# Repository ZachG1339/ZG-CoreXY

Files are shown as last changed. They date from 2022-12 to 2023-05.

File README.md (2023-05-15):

# CoreXY

Arduino Based Core XY assembly. All 3D printed components are custom made for this assembly but are compatible with 20x20 extrusion.

The core xy method is one of many methods to move a "head" anywhere in a set MxN rectangular 2D plane. It utilizes two timing belts connected to two independent stepper motors. The belts all begin and end at the head, moving it in any direction with the combined torque of both steppers. 

## V1:

The quick background behind V1 is it was officially intended to be the arduino project for a C++ programming class. Using that as my excuse and hard 3 week timeline I tried to make a functional prototype that technically fit the project parameters, hence the joystick control and not automation.

Designed and coded to move a continuous servo attached to the head using the arduino joystick module. 

#### Known Defects:
- Motor overheating issue
  - likely caused by lack of ventilation in the motor mounts however load may have exceeded the motors I acquired for this prototype

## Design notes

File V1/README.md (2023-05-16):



### Required Materials:
(N and M are arbitrary constants)
- ~500g of PLA and 3D printer access
#### Frame:
- 20x20mm extrusion:
  - 2 (N + 1.57)" for width
  - 2 M" for length -> required only for structural stability
  - 4 2" as vertical supports
  - 1 (M - 1.6)" as the X axis
#### Linear Motion:
- [GT2 6mm timing belt](https://www.amazon.ca/gp/product/B08PKPK4D8/ref=ppx_yo_dt_b_asin_title_o00_s01?ie=UTF8&psc=1) -> length depends on extrusion length -> approximately 2M + 2N 
- [8 bearing idlers](https://www.amazon.ca/gp/product/B07P9M6BRC/ref=ppx_yo_dt_b_asin_title_o00_s01?ie=UTF8&psc=1) (5mm bore, 12mm inner diameter, 18mm outer diameter)
- [2 GT2 pulleys](https://www.amazon.ca/gp/product/B08PKPK4D8/ref=ppx_yo_dt_b_asin_title_o00_s01?ie=UTF8&psc=1)
- [9 Bearing wheels](https://www.amazon.ca/gp/product/B07Q5WN3GK/ref=ppx_yo_dt_b_asin_title_o00_s00?ie=UTF8&psc=1)
- 11 M5 40mm bolts
- 18 M5 nuts or 9 M5 lock nuts
- 4 13mm segements of smooth 5mm diameter shaft

(note: M5 items can be comfortably replaced with 3/16" equivalents)


#### Electrical:
- 2 identical NEMA 17 stepper motors
- Arduino Uno R3 or Mega R3
- DC Power Supply -> compatible with motors and drivers
- Generous supply of F-M and M-M DuPont (jumper) wires -> at least 6 and 10 respectively

## Additional Materials:
- Adafruit Motor Shield V2 -> max per motor current 1.2 A
  - [Adafruit Documentation](https://learn.adafruit.com/adafruit-motor-shield-v2-for-arduino)
- 1 [SG90 servo motor](https://www.amazon.ca/Micro-Servos-Helicopter-Airplane-Controls/dp/B07MLR1498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)
- 5 F-M jumper wires
- 1 Arduino joystick module

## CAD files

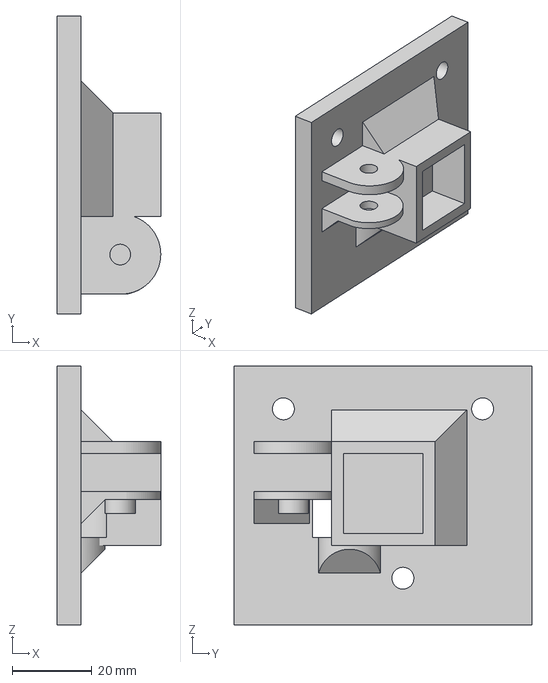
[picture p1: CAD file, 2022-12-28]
V1/Print Files/V1-2_L Carrage.3mf
26.0 x 74.8 x 65.0 mm

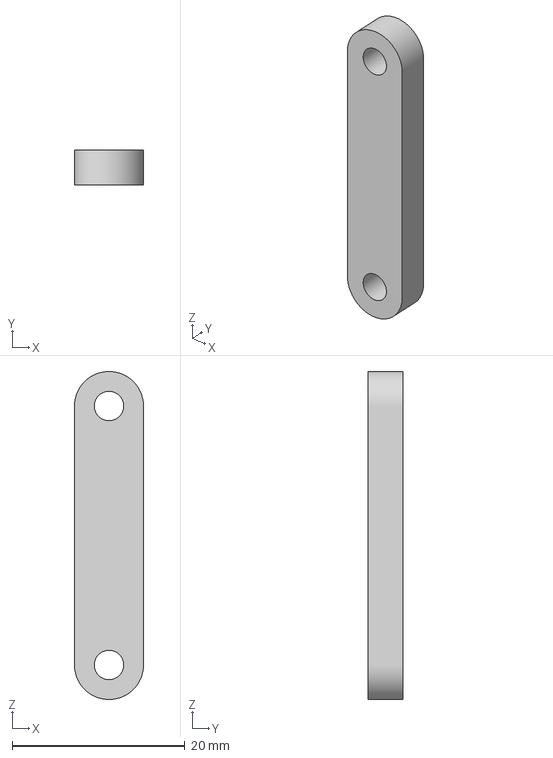
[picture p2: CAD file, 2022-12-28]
V1/Print Files/V1-1_C Clamp.3mf
8.00 x 4.00 x 38.0 mm

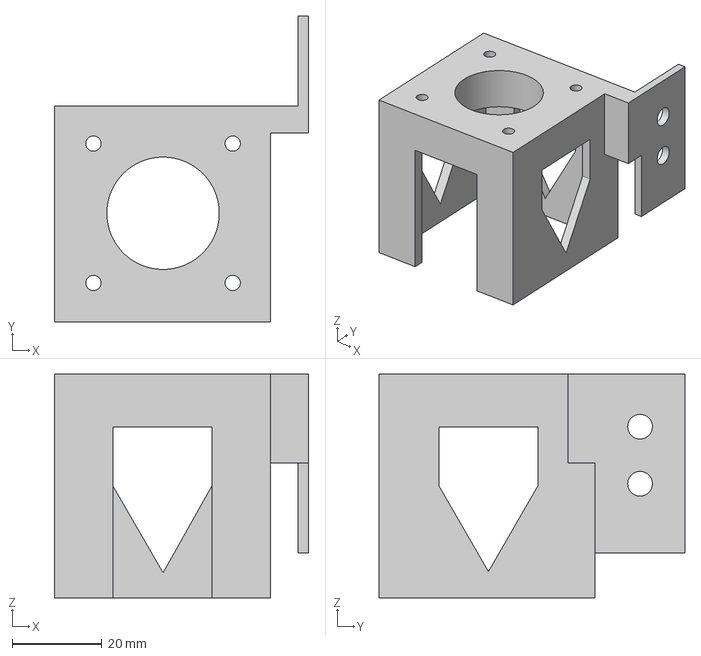
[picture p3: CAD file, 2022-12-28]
V1/Print Files/V1-1_R Motor.3mf
56.6 x 68.1 x 49.8 mm

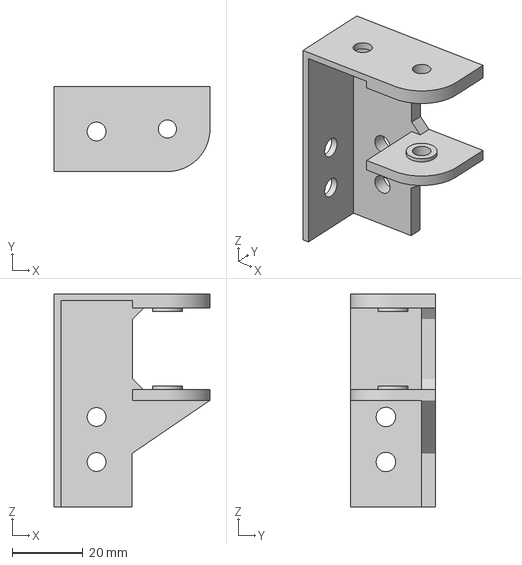
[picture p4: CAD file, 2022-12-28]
V1/Print Files/V1-3_L Idlers.3mf
44.0 x 24.0 x 60.1 mm

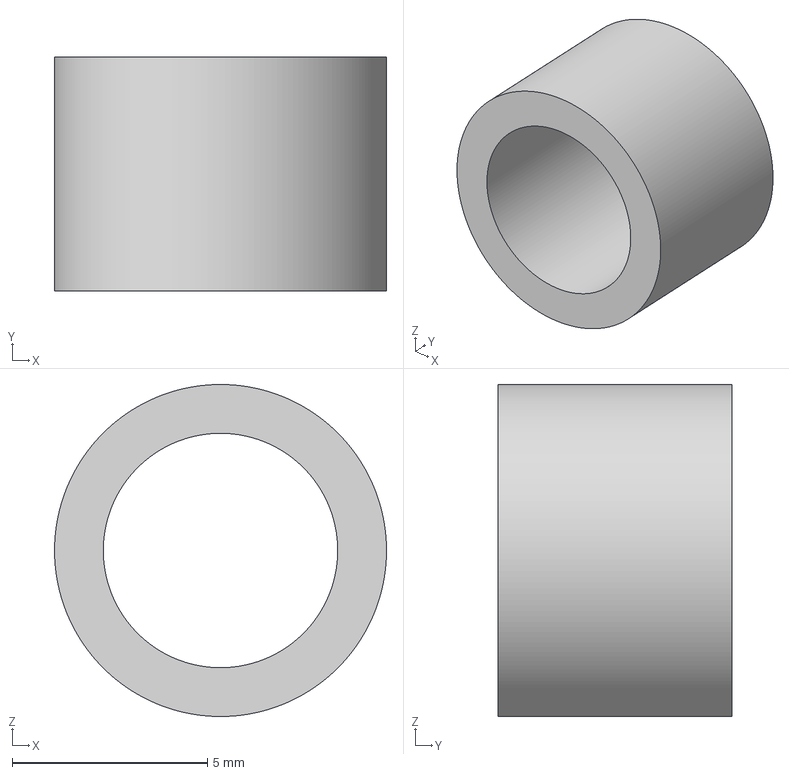
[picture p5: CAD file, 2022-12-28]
V1/Print Files/V1-1_C Spacer.3mf
8.50 x 6.00 x 8.50 mm

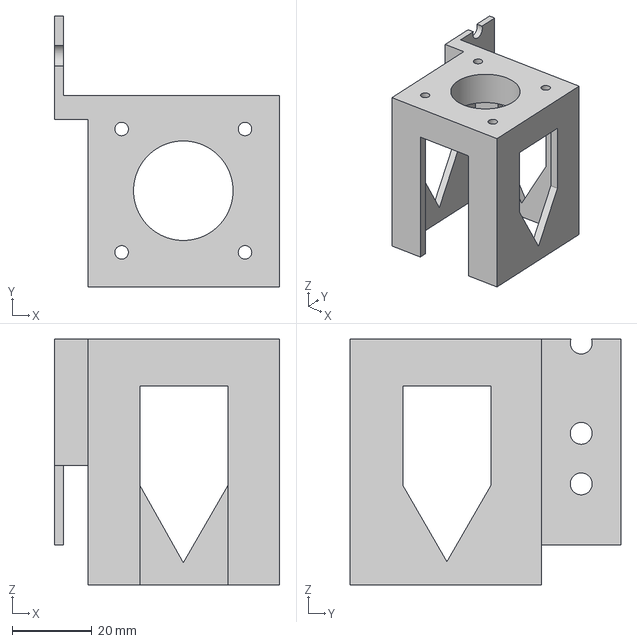
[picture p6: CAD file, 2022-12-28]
V1/Print Files/V1-1_L Motor.3mf
56.6 x 68.1 x 61.8 mm

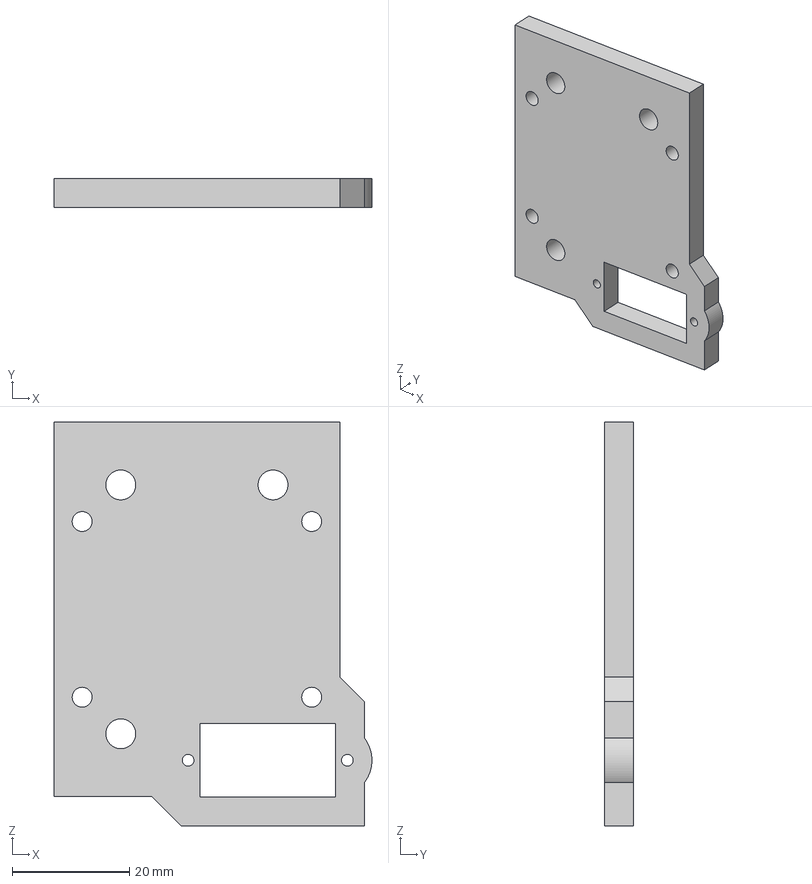
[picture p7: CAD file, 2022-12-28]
V1/Print Files/V1-1_C Carrage.3mf
54.3 x 5.00 x 69.0 mm

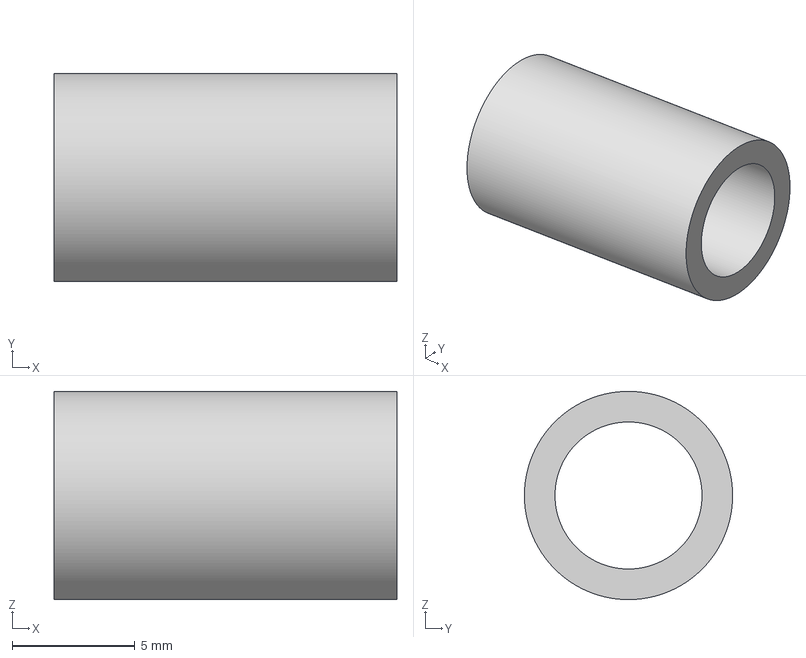
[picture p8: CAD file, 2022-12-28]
V1/Print Files/V1-3_RL Spacer.3mf
14.0 x 8.50 x 8.50 mm

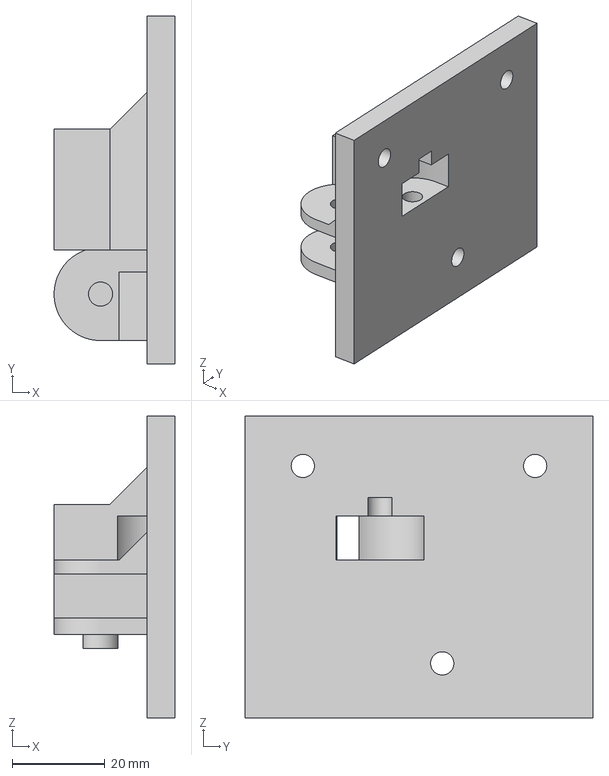
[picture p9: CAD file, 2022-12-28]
V1/Print Files/V1-2_R Carrage.3mf
26.0 x 74.8 x 65.0 mm

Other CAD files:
V1/Print Files/V1-3_R Idlers.3mf

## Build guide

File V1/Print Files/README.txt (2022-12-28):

Print instructions:

(based on ender 3 pro performance)

All files will work on standard 0.2mm or less layer height with a 0.4mm nozzle or smaller

- NO SUPPORTS
- Print Speed: 25 - 70 mm/s 
- infill: 20-40%
- Walls: 1.2mm minimum
- Reccomended Material: PLA -> 215 C end temperature

Feel free to play with more settings however these were pragmatic for me

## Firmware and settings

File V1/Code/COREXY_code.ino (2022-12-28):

//information for the adafruit motor shield and using 2 steppers simultaneously:
// https://github.com/adafruit/Adafruit_Motor_Shield_V2_Library 
// NOTE: For my servo parked at input 89 NOT 90 (manufacturing error I didn't have time to fix). 
//       So when 89 is written to servo1 that means park

// Other Important Sources in README document

// Required libraries
#include <Servo.h>
#include <ezButton.h>
#include <AccelStepper.h>
#include <Adafruit_MotorShield.h>

// initiation of joystick properties
#define joyX_Pin A0
#define joyY_Pin A1

// initial storage variables for joystick inputs
int joyX;
int joyY;

// joystick button pin number
const int pushButtonPin = 2;

// initiaion of Jotstick Button
ezButton button(pushButtonPin);
int bValue = 0;

// variable dictating what keybinds are active
//  1 = head movement
// -1 = servo movement
int controlState = 1;


// initiation of servo
Servo servo1;
int Park = 88;
int sSpeed = Park;



// creation of motorshield object
Adafruit_MotorShield AFMS(0x60); 

// Initiation of motorshield communication with the steppers (steps per revolution, port)
// Using 17HS4023 stepper motors with 1.8 degrees per step
Adafruit_StepperMotor *ADA_Left_Step = AFMS.getStepper(200, 1); 
Adafruit_StepperMotor *ADA_Right_Step = AFMS.getStepper(200, 2);


// creation of functions that step motors forward and backward with standard Adafruit library
// AccelStepper requires these functions for initiation

// wrappers for the Left Motor
void Left_forwardstep() {
  ADA_Left_Step->onestep(FORWARD, DOUBLE);
}
void Left_backwardstep() {
  ADA_Left_Step->onestep(BACKWARD, DOUBLE);
}
// wrappers for the Right Motor
void Right_forwardstep() {
  ADA_Right_Step->onestep(FORWARD, DOUBLE);
}
void Right_backwardstep() {
  ADA_Right_Step->onestep(BACKWARD, DOUBLE);
}

// Creation of Accel Stepper objects
// These are what will actually control the stepper motors
// and will allow for simultaneous control
AccelStepper Left_Step(Left_forwardstep, Left_backwardstep);
AccelStepper Right_Step(Right_forwardstep, Right_backwardstep);

// Final Stepper Speed Variables  
int V_Left = 0;
int V_Right = 0;


void setup() {
  // put your setup code here, to run once:

  AFMS.begin(); //Begin communication with the motor shield

  // set up parameters for stepper motor movement
  Left_Step.setSpeed(100); //steps
  Left_Step.moveTo(100); // steps from initial
  Left_Step.setMaxSpeed(3000); // steps/s
  Left_Step.setAcceleration(100.0); // steps/s^2
  
  Right_Step.setSpeed(100);
  Right_Step.moveTo(100); 
  Right_Step.setMaxSpeed(3000);
  Right_Step.setAcceleration(100.0);

  // initiation of servo and Arduino Communication
  servo1.attach(10);
  Serial.begin(9600);
  servo1.write(Park); // 89 was closest to park for my servo

  // sets button delay
  button.setDebounceTime(1);

  // Set mode of Joystick Analogue Axis
  pinMode(joyX_Pin, INPUT);
  pinMode(joyY_Pin, INPUT);
}

void loop() {
  // put your main code here, to run repeatedly:

  // check for button
  button.loop();
  bValue = button.getState();

  // code to switch keybinds
  // stops all motors/actuators and changes keybinds
  if(button.isReleased()) {
    Left_Step.moveTo(Left_Step.currentPosition());
    Right_Step.moveTo(Right_Step.currentPosition());
    Left_Step.setSpeed(0);
    Right_Step.setSpeed(0);
    servo1.write(89);
    
    controlState = -controlState;
    delay(1000);
  }

  // read and process joystick inputs so (0,0) is the center position
  joyX = analogRead(joyX_Pin);
  joyY = analogRead(joyY_Pin);
  joyX -= 513; 
  joyY -= 513;

  // convert joystick x:y to velocity of Left and Right stepper motors
  // equations found via linear transformation in README document
  V_Left = (2000.0/512.0)*(joyX + joyY);
  V_Right = (2000.0/512.0)*(joyX - joyY);

  // conditional statement dictating active keybinds
  
  // head movement only
  // code to move the head around the xy plane while the servo stays still
  if(controlState == 1){
    
    // set target amount of steps from current positions to move
    // magnitude and direction doesn't matter so long as the motors think they must move somewhere
    Left_Step.move(100);
    Right_Step.move(100);

    // set speed to targets
    // ratio same as x:y ratio of joystick
    // motors will be moved after the conditional at the end
    Left_Step.setSpeed((int)V_Left);
    Right_Step.setSpeed((int)V_Right);
    

    //servo stays still under these keybinds
    servo1.write(Park);
 
  }

  // servo movement only
  // code to keep the head still while the servo is moved
  else{
    
    //make the stepper motors stay still
    Left_Step.moveTo(Left_Step.currentPosition());
    Right_Step.moveTo(Right_Step.currentPosition());
    Left_Step.setSpeed(0);
    Right_Step.setSpeed(0);

    // convert X axis movement to the 180 unit range of servo speed
    sSpeed = (int)(joyX + 513)*(180.0/1024.0);

    // run servo
    servo1.write(sSpeed);
  }
  // illustrate which keybinds are active
  Serial.println(controlState);

  // runs motors at speed specified earlier in the loop under "head movement only" keybinds
  Left_Step.runSpeed();
  Right_Step.runSpeed();
}

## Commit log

2022-12-28 Rename Print Guide.txt to README.txt
2023-05-15 Create Materials
2023-05-15 Update and rename Materials.md to README.md
